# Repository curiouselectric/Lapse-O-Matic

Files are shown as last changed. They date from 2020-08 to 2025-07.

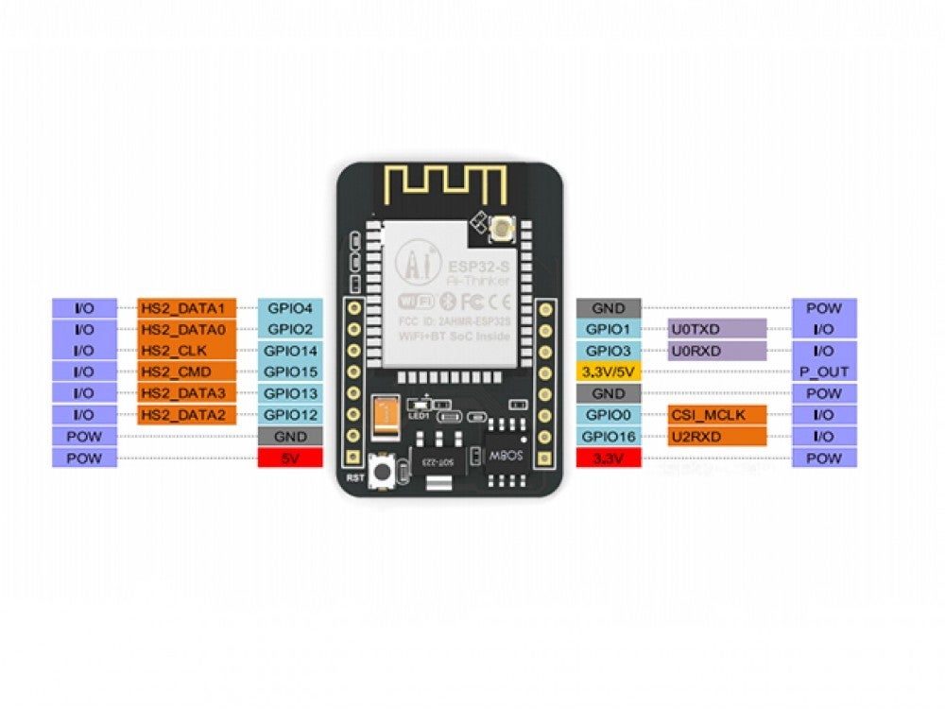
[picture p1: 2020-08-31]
Lapse-O-Matic_INFO/Datasheets/AI Tinker ESP32_CAM Info/ESP32_CAM_PINOUT.jpg

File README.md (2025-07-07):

# Solar Powered ESP32 Camera For Wildlife and Time-Lapse
This is code, PCB and enclosure design for an ESP32_CAM based, solar powered wildlife camera

This unit is based on the ESP32_CAM.

Code has been written to upload onto the ESP32.

Control of the unit is through a "settings.txt" file on the SD card.

The unit can either be in "LAPSE" mode (where it wakes up every set period and takes a photo/number of photos) or it can be in "TRIGGER" mode where it will take a number of photos when the unit is triggered. It will then go back to sleep.

Triggering can either be done with a PIR, or with an external switch.

This unit has an input for a small solar panel to recharge an 18650 Li Ion cell, so it can be left for remote monitoring.

A flash can be implemented, with a start and stop delay to adjust shadow effects.

This code relies heaviliy on the following tutorials and information:

* https://techtutorialsx.com/2020/06/27/esp32-connecting-to-sd-card/
* https://randomnerdtutorials.com/esp32-cam-take-photo-save-microsd-card/
* https://www.olimex.com/Products/IoT/ESP32/ESP32-CAM/
* https://marksbench.com/electronics/esp32-cam-low-power-trail-camera/
* https://hackaday.com/2020/05/18/esp32-trail-camera-goes-the-distance-on-aa-batteries/
* https://randomnerdtutorials.com/esp32-cam-ai-thinker-pinout/
* https://dronebotworkshop.com/esp32-cam-intro/

## ESP32 Code

Please follow these instructions for setting up your arduino IDE to upload code to the ESP32_CAM.

There is no USB connection to the ESP32_CAM, so I used this nice programmer from Tindie (around £10 UK):
https://www.tindie.com/products/bitluni/cam-prog/

The code starts by reading the settings.txt file on the root directoy of the SD card. If the SD card fails to mount, then the unit will go to default settings, which will mean sleeping for 10 seconds then trying the SD card again.
If there is no settings.txt file then the unit will use the default values (stored in the config.h page of the firmware).

## Settings file

Here is an example settings.txt file:

    // Adjust these settings as required: //
    FLASH_FLAG=1
    NUMBER_PHOTOS=4
    TIME_TO_SLEEP=800
    MODE=TRIGGER
    PHOTO_DELAY=250
    FLASH_START_DELAY=100
    FLASH_STOP_DELAY=100
    DEBUG_FLAG=1
    DEBUG_PHOTO=1
    // END OF SETTINGS - LEAVE THIS LINE  //

* FLASH_FLAG - Use a flash with the photo? (0 (OFF) or 1 (ON))
* NUMBER_PHOTOS - How many photos to take when waking up?
* TIME_TO_SLEEP - How long (in seconds) between wake-ups (when in SLEEP mode)
* MODE - The mode to use is either LAPSE (wake up every TIME_TO_SLEEP seconds) or TRIGGER (either wake up on PIR trigger or external trigger)
* PHOTO_DELAY - delay (in milli Seconds) between taking the photos.
* FLASH_START_DELAY - Flash will switch on then wait this time before taking photo (in milli Seconds)
* FLASH_STOP_DELAY - Flash will be on and wait this time after taking photo (in milli Seconds)
* DEBUG_FLAG - See debug info on serial port (0 (OFF) or 1 (ON))
* DEBUG_PHOTO - See debug info on serial port (0 (OFF) or 1 (ON))

*Note: Spaces can be used in the WIFI SSID. Do not use spaces around the equals sign.*

## Solar Power

This unit has a sinlge 18650 lithium polymer cell for power. This has a battery charging circuit using one cell PV module.

Based upon the BQ24210 800mA, single-input, single cell Li-ion Solar battery charger from Texas Instruments:

https://www.ti.com/sitesearch/docs/universalsearch.tsp?searchTerm=BQ24210#q=BQ24210&t=everything&linkId=1

## PCB design

PCB is designed in KiCAD.

A Real Time Clock (RTC) has been added to use as a timestamp on the photo files. This can also be used for the timing of the unit wake up.

## WiFi Upload

This unit uses ReadyMail from mobizt to send photos via an email SMTP server to any email address. You must set up your own email from which to send photos (I used gmail).

This is not always totally reliable, especially if any reception issues. But photos are still saved on the SD card.

## More information

There is lots more about this project at this blog post:

[*https://www.curiouselectric.co.uk/blogs/blog/prototyping-a-wildlife-camera**](https://www.curiouselectric.co.uk/blogs/blog/prototyping-a-wildlife-camera)

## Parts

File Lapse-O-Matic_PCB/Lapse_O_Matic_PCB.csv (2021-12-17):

Source: | G:\My Drive\Work - Kits\PRODUCTS\Prototype\Wildlife Camera\GITHUB\Wildlife_ESP_Cam\Wildlife_Cam_PCB\Lapse_O_Matic_PCB.sch
Date: | 19/08/2021 15:55:53
Tool: | Eeschema (5.1.10)-1
Component Count: | 38
Ref | Value | Footprint | Datasheet | Manufacturer | Vendor
C1 | 1uf | REInnovationFootprint:C_1V7_TH | ~
C3 | 1uf | REInnovationFootprint:C_1V7_TH | ~
D1 | ZENER | REInnovationFootprint:TH_Diode_3
D4 | TRIG? | REInnovationFootprint:TH_LED-5MM | ~
D5 | FLASH | REInnovationFootprint:TH_LED-5MM | ~
D6 | FLASH | REInnovationFootprint:TH_LED-5MM | ~
D7 | FLASH | REInnovationFootprint:TH_LED-5MM | ~
D8 | FLASH | REInnovationFootprint:TH_LED-5MM | ~
J1 | PIR | REInnovationFootprint:SIL-3_PIR_SENSOR | ~
J2 | TRIG | REInnovationFootprint:SIL-3_lg_pad | ~
J3 | RTC_DS3231 | REInnovationFootprint:TH_RTC_MODULE_SM | ~
J4 | PROG | REInnovationFootprint:TH_6x1_CONN | ~
J5 | PROG_EN | REInnovationFootprint:TH_Pin_Header_Straight_1x02 | ~
J6 | LOGO1 | CuriousElectric3:TCEC_Words_13mm | ~
J7 | LOGO2 | CuriousElectric3:2019_011_16_CuriousElectricCompany_Logo_Round_Logo_No_words_KiCAD_10mm_PCBLogo | ~
J8 | PCB | REInnovationFootprint:PCB_SolarChargerPCB40x80 | ~
J9 | LOGO3 | REInnovationGraphics:lapseomatic logo | ~
J10 | POWER | REInnovationFootprint:SIL-2_screw_terminal | ~
J11 | LOGO4 | REInnovationGraphics:lapseomatic logo_20x6mm | ~
Q1 | 2N3904 | REInnovationFootprint:NPN_BC337 | transistors/bipolar/*.*
Q2 | 2N3904 | REInnovationFootprint:NPN_BC337 | transistors/bipolar/*.*
Q3 | BD135 | REInnovationFootprint:TO220_BD135 | ~
R1 | 1k | REInnovationFootprint:TH_Resistor_1 | ~
R2 | 10k | REInnovationFootprint:TH_Resistor_1 | ~
R6 | 1k | REInnovationFootprint:TH_Resistor_1 | ~
R8 | 10k | REInnovationFootprint:TH_Resistor_1 | ~
R9 | 330 | REInnovationFootprint:TH_Resistor_1 | ~
R10 | 10k | REInnovationFootprint:TH_Resistor_1 | ~
R11 | 1k | REInnovationFootprint:TH_Resistor_1 | ~
R12 | 10k | REInnovationFootprint:TH_Resistor_1 | ~
R13 | 100 | REInnovationFootprint:TH_Resistor_1 | ~
R14 | 100 | REInnovationFootprint:TH_Resistor_1 | ~
R15 | 100 | REInnovationFootprint:TH_Resistor_1 | ~
R16 | 100 | REInnovationFootprint:TH_Resistor_1 | ~
SW1 | POWER | REInnovationFootprint:SW_SPDT_R_Angle_ALIEX
SW2 | TRIGGER | REInnovationFootprint:SW_PUSH_SMALL_lg_pad | ~
U1 | MCP1826S-3302 | REInnovationFootprint:TO220_MCP1826S | http://docs-europe.electrocomponents.com/webdocs/137e/0900766b8137eda2.pdf
U3 | ESP32_CAM | REInnovationFootprint:ESP32_CAM

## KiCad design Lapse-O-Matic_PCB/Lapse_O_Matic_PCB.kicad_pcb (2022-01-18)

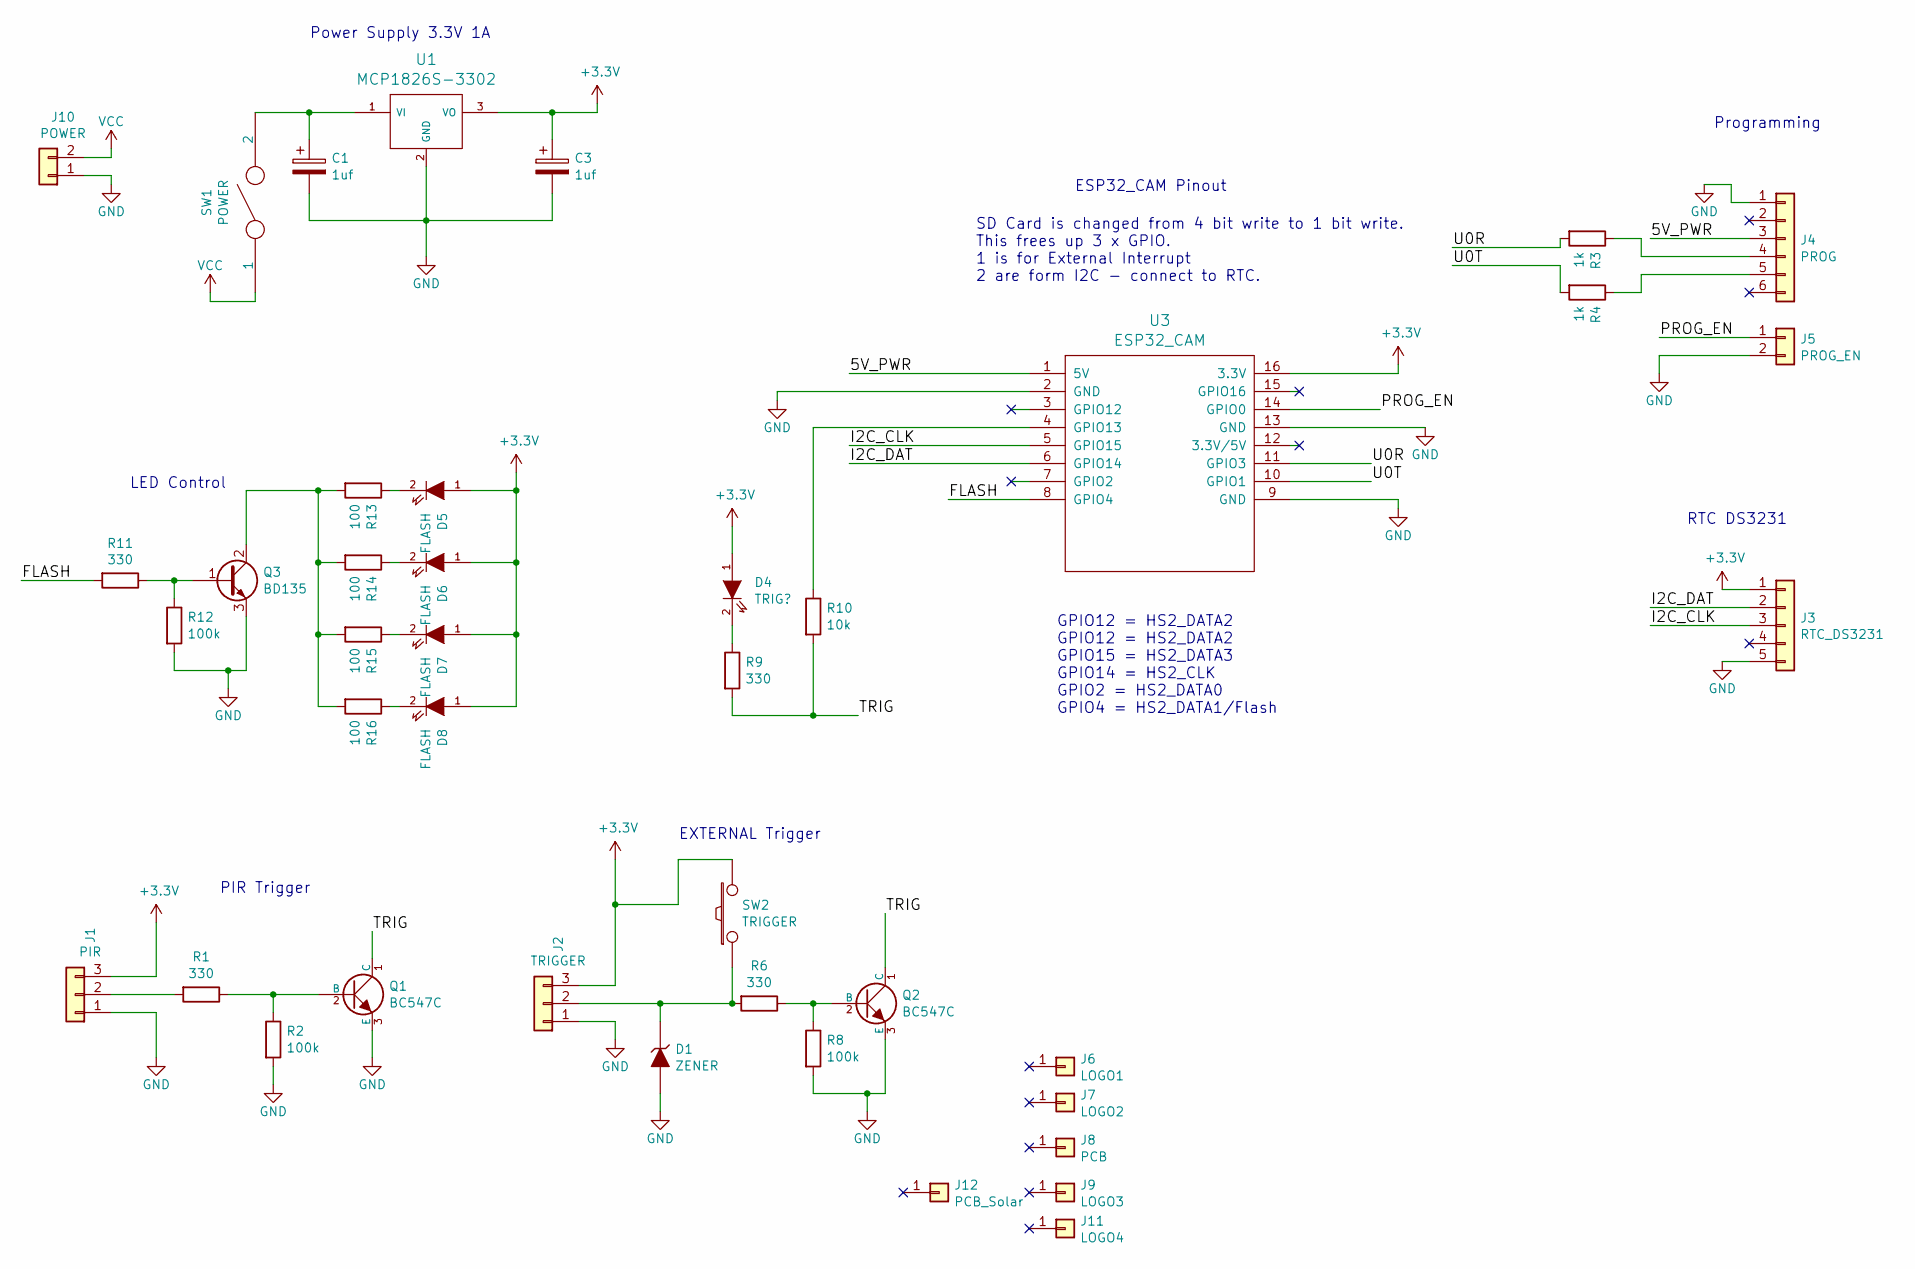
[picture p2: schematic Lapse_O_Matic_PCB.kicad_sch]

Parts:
C1, C3: 1uf; C_1V7_TH
D1: ZENER; TH_Diode_3
D4: TRIG?; TH_LED-5MM
D5, D6, D7, D8: FLASH; TH_LED-5MM
J1: PIR; SIL-3_PIR_SENSOR
J2: TRIGGER; SIL-3_screw_terminal
J3: RTC_DS3231; TH_RTC_MODULE_SM
J4: PROG; TH_6x1_CONN
J5: PROG_EN; TH_Pin_Header_Straight_1x02
J6: LOGO1; TCEC_Words_13mm
J7: LOGO2; 2019_011_16_CuriousElectricCompany_Logo_Round_Logo_No_words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
J8: PCB; PCB_Lapse-O-Matic
J9: LOGO3; lapseomatic logo_20x6mm
J10: POWER; SIL-2_screw_terminal
J11: LOGO4; lapseomatic logo_20x6mm
J12: PCB_Solar
Q1, Q2: BC547C; NPN_BC337
Q3: BD135; TO220_BD135
R1, R6, R9, R11: 330; TH_Resistor_1
R2, R8, R12: 100k; TH_Resistor_1
R3, R4: 1k; TH_Resistor_1
R10: 10k; TH_Resistor_1
R13, R14, R15, R16: 100; TH_Resistor_1
SW1: POWER; SW_SPDT_R_Angle_ALIEX
SW2: TRIGGER; SW_PUSH_SMALL_lg_pad
U1: MCP1826S-3302; TO220_MCP1826S
U3: ESP32_CAM

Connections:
+3V3: C3.1, D4.1 (A), D5.1 (A), D6.1 (A), D7.1 (A), D8.1 (A), J1.3, J2.3, J3.1, SW2.2, U1.3 (VO), U3.16 (3.3V)
/5V_PWR: J4.3, U3.1 (5V)
/FLASH: R11.2, U3.8 (GPIO4)
/I2C_CLK: J3.3, U3.5 (GPIO15)
/I2C_DAT: J3.2, U3.6 (GPIO14)
/PROG_EN: J5.1, U3.14 (GPIO0)
/TRIG: Q1.1 (C), Q2.1 (C), R9.2, R10.2
/U0R: R3.2, U3.11 (GPIO3)
/U0T: R4.2, U3.10 (GPIO1)
GND: C1.2, C3.2, D1.2 (A), J1.1, J2.1, J3.5, J4.1, J5.2, J10.1, Q1.3 (E), Q2.3 (E), Q3.3 (E), R2.2, R8.2, R12.2, U1.2 (GND), U3.2 (GND), U3.9 (GND), U3.13 (GND)
unnamed: C1.1, SW1.2, U1.1 (VI)
unnamed: D1.1 (K), J2.2, R6.2, SW2.1
unnamed: D4.2 (K), R9.1
unnamed: D5.2 (K), R13.1
unnamed: D6.2 (K), R14.1
unnamed: D7.2 (K), R15.1
unnamed: D8.2 (K), R16.1
unnamed: J1.2, R1.2
unnamed: J4.4, R3.1
unnamed: J4.5, R4.1
unnamed: Q1.2 (B), R1.1, R2.1
unnamed: Q2.2 (B), R6.1, R8.1
unnamed: Q3.1 (B), R11.1, R12.1
unnamed: Q3.2 (C), R13.2, R14.2, R15.2, R16.2
unnamed: R10.1, U3.4 (GPIO13)
VCC: J10.2, SW1.1

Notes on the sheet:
LED Control
RTC DS3231
Programming
ESP32_CAM Pinout
PIR Trigger
Power Supply 3.3V 1A
SD Card is changed from 4 bit write to 1 bit write. This frees up 3 x GPIO. 1 is for External Interrupt 2 are form I2C - connect to RTC.
EXTERNAL Trigger
GPIO12 = HS2_DATA2 GPIO12 = HS2_DATA2 GPIO15 = HS2_DATA3 GPIO14 = HS2_CLK GPIO2 = HS2_DATA0 GPIO4 = HS2_DATA1/Flash

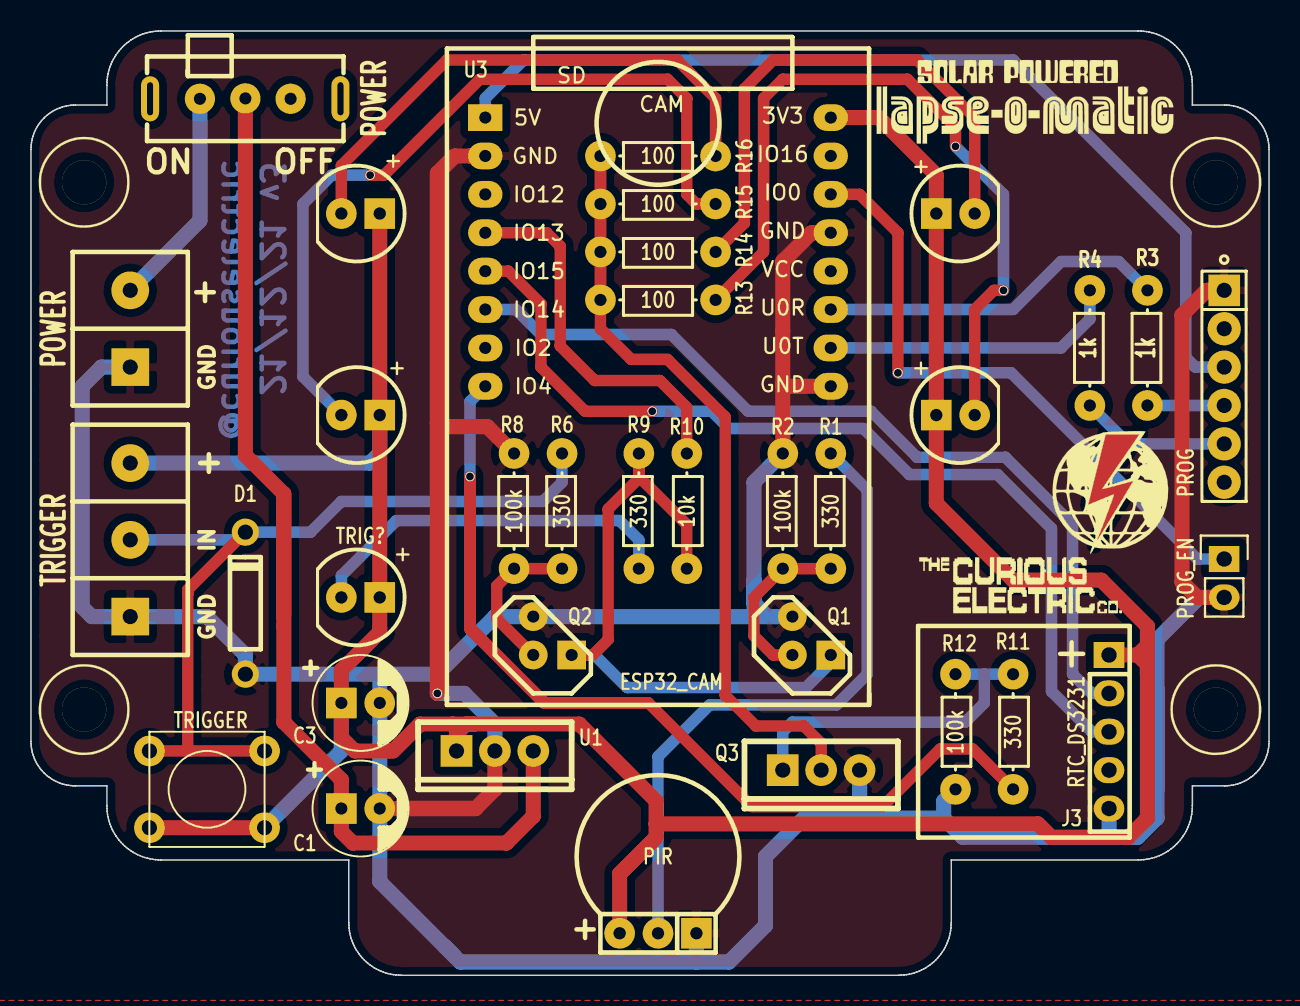
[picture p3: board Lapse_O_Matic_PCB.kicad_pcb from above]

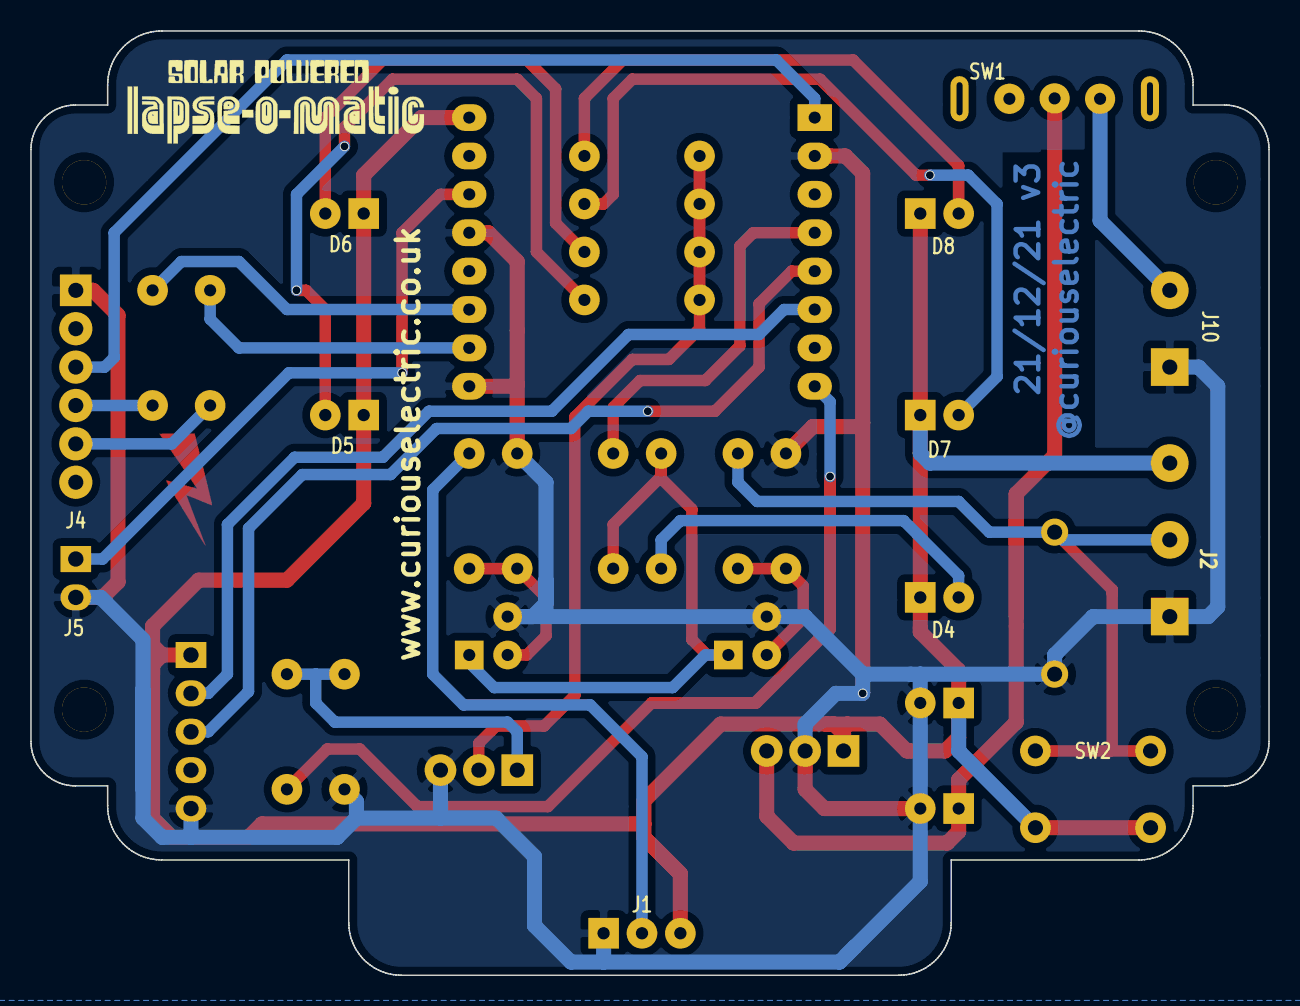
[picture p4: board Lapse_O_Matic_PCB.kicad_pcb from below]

Board: 2 copper layers, 81.9 x 62.5 mm, 40 parts (3 on the bottom side), 26 nets.

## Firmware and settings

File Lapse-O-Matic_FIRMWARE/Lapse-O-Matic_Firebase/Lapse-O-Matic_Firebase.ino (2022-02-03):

/* ********* ESP32_CAM Wildlife Camera Unit **************************

    by Matt Little
    The Curious Electric Company (www.curiouselectric.co.uk)
    hello@curiouselectric.co.uk
    17/12/2021
    This code is Open Source - please adjust and use as you would like.
    Please ensure accreditation
    (although most of this code is based on work of others - see list below).

    More information (full files and firmware) is here:
    https://github.com/curiouselectric/Lapse-O-Matic

    Idea for this code:
    Unit is solar powered with a lithium ion battery bank 18650 cell
    Unit wakes up with a PIR sensor or with external interrupt (via switched contacts) or via sleep mode.
    Reads each time the config file from the SD card - this tells it what mode to run in and other parameters.
    Need a "settings.config.txt" file on the SD card with thes config values.

    At that point the unit takes a number of photos with a delay between them
    Unit can wake up with either LAPSE or TRIGGER.
    LAPSE will be every LAPSE seconds. TRIGGER will be on PIR or external switch.

    It uses a real time clock (RTC) to add a timestamp to the photo image.
    It will update the RTC to NTP time (UTC) if the unit connects to wifi at any point.
    This is checked each time it connects.

    This code now uploads the image(s) to Firebase (https://firebase.google.com/) for photo storage.
    Following this tutorial (caefully) for setting up your firebase account and details:
    https://randomnerdtutorials.com/esp32-cam-save-picture-firebase-storage/

    ***TO PROGRAM: Set Board to "AI Thinker ESP32-CAM"***

    Some Information that has been very useful
    https://randomnerdtutorials.com/esp32-cam-take-photo-save-microsd-card/
    https://www.olimex.com/Products/IoT/ESP32/ESP32-CAM/
    https://marksbench.com/electronics/esp32-cam-low-power-trail-camera/
    https://hackaday.com/2020/05/18/esp32-trail-camera-goes-the-distance-on-aa-batteries/
    https://randomnerdtutorials.com/esp32-cam-ai-thinker-pinout/
    https://dronebotworkshop.com/esp32-cam-intro/

    This new code uploads to firebase. Following this tutotorial:
    https://randomnerdtutorials.com/esp32-cam-save-picture-firebase-storage/

    Must include:
    Firebase Arduino Client Library for ESP8266 and ESP32 by Mobitz
    https://github.com/mobizt/Firebase-ESP-Client


    Done:
    Sort out the LED on (at low glow level)? - This is solved.
    Sort out flash LED - only works on first reprogram - This is solved.
    Sort out interrupt via PIR unit - This is solved.
    Flash on/off (boolean ) is not working? - Sorted
    Sort out RTC for file name - done. I2C shared pins.
    Sort out file names.
    Sort out reprogramming with FTDI/USB
    Sort out running all at 3.3V. Works with low drop out regulator.
    What happens if no RTC connected? - reverts to other filename with a counter
    Report Error to log file. - this happens when camera does not start with timestamp
    if no RTC: need to sort out naming as it's overwriting the same one. - DONE
    Send photos via email if on wifi (https://randomnerdtutorials.com/esp32-cam-send-photos-email/)
    https://rntlab.com/question/esp32-cam-send-email-with-attachment-from-sd-card-problem-no-attachment-in-email/
    Issue with SD_MMC and sending info with SD.
    Need to change to use SD_MMC for 1-bit writing to SD card

    To do:
    Need error feedback - flash 1 for OK, 2 for internet not OK, 3 for SD error, 5 for camera sync error
    Add configuration via WifiManager (?)
    Add voltage measurement to check battery is OK - ADC? - Not easy with so few IO pins
    Shut down everything in sleep mode - at present using 5.8mA in Sleep!!!

    Sleep issues:
    Takes around 5mA (actually 4.6mA)
    Looks like LDO is issue:
    https://diyi0t.com/reduce-the-esp32-power-consumption/
    https://www.hackster.io/dontsovcmc/esp32-cam-current-measure-87c18f
    I dont need LDO on my board, as I already have one!
    Removed LDO - down to 2.6mA
    Removed camera - down to 0.47mA // Can I set GPIO to switch this off?

    Added this line:
    pinMode(OUTPUT_OPEN_DRAIN, GPIO_NUM_12);pinMode(OUTPUT_OPEN_DRAIN, GPIO_NUM_15);
    Now down to about 1.9mA 2.4mA (maybe 2.4mA after a while)

    Need to shut down the camera - uses about 1.9mA all the time...
    digitalWrite(PWDN_GPIO_NUM, HIGH);
    Does not do anything
    https://issueexplorer.com/issue/espressif/esp32-camera/247

    From this:
    https://github.com/espressif/esp32-camera/issues/33
    camera_disable_out_clock();
    and in camera config
    extern "C" { esp_err_t camera_enable_out_clock(camera_config_t *config); void camera_disable_out_clock(); }
    This does not seem to do much!

*/

#include <esp_camera.h>
#include <FS.h>
#include <SPI.h>
#include "SD_MMC.h"
#include <Preferences.h>
#include <Arduino.h>
#include <SPIFFS.h>
#include <WiFi.h>

#include <Firebase_ESP_Client.h>
//Provide the token generation process info.
#include <addons/TokenHelper.h>

#include "config.h"
#include "camera_pins.h"
#include "Esp.h"
#include "utilitiesDL.h"
#include "lapseomatic.h"

#include "driver/sdmmc_host.h"
#include "driver/sdspi_host.h"

// Date and time functions using a DS3231 RTC connected via I2C and Wire lib
#include <Wire.h>
#include "RTClib.h"
#include "time.h"
RTC_DS3231 rtc;

#include "soc/soc.h"           // Disable brownout problems
#include "soc/rtc_cntl_reg.h"  // Disable brownout problems
#include "driver/rtc_io.h"

// The ESP32 EEPROM library is deprecated. Use the Preferences library instead.
Preferences preferences;
settings  settings_config;              // This holds the settings info from the SD card
// Configure the camera with the pins defined above and recommended settings for xclk, led_c, and format.
camera_config_t config;

// Create a variable to hold the picture number. Since the SD card is formatted FAT32, the maximum number of files
// there can be is 65534, so a 16-bit unsigned number will be fine.
// Want to store this in 'sleep' protected memory
uint16_t PIC_COUNT = 0;
String filename = "";       // This holds the date string for the filename.

String PHOTO_NAME[5];          // Holds the name of the photo to send. Actually want array of names of photos to send.... Max photos to send = 5

//Define Firebase Data objects
FirebaseData fbdo;
FirebaseAuth auth;
FirebaseConfig configF;

// For NTP time server
const char* ntpServer = "pool.ntp.org";
const long  gmtOffset_sec = 0;
const int   daylightOffset_sec = 0;


void setup()
{
  WRITE_PERI_REG(RTC_CNTL_BROWN_OUT_REG, 0);  //disable brownout detector
  Serial.begin(115200);
  //Print the wakeup reason for ESP32
  print_wakeup_reason();
  DEBUGLN(settings_config.DEBUG_FLAG, "Starting");
  switch_off_flash_LED(); // Ensure LED is OFF to start.

  bool rtc_flag = true;

  initSPIFFS();
  clearSPIFFS();  // If files in SPIFFS then delete them!

  // Lets try reading/writing to I2C
  // Start the I2C interface
  if (! Wire.begin(I2C_SDA, I2C_SCL)) {
    // If the RTC does not start,
    // Then carry on, but without correct filename.
    DEBUGLN(settings_config.DEBUG_FLAG, "Couldn't find RTC");
    rtc_flag = false;
  }

  if (! rtc.begin()) {
    // If the RTC does not start, wait for a little while (1 sec?)
    // Then carry on, but without correct filename.
    delay(200);
    DEBUGLN(settings_config.DEBUG_FLAG, "Couldn't find RTC");
    rtc_flag = false;
    //abort();
  }
  if (rtc_flag == true)
  {
    if (rtc.lostPower())
    {
      // Here we get the date and time from the SD card??
      DEBUGLN(settings_config.DEBUG_FLAG, "RTC lost power, let's set the time!");
      // When time needs to be set on a new device, or after a power loss, the
      // following line sets the RTC to the date & time this sketch was compiled
      rtc.adjust(DateTime(F(__DATE__), F(__TIME__)));
      // This line sets the RTC with an explicit date & time, for example to set
      // January 21, 2014 at 3am you would call:
      //rtc.adjust(DateTime(2020, 12, 5, 11, 44, 0));
    }
    DateTime now = rtc.now();
    // Set the date with date and time with the data, to use as filename later.
    filename = "D" + (String)now.year() + "_" + (String)now.month() + "_" +
               (String)now.day() + "_T" + (String)now.hour() + "_" + (String)now.minute() + "_" + (String)now.second();
  }
  else
  {
    // RTC is not attached so cannot use it!
    filename = "NO_RTC_";
  }

  // *************** SORT OUT THE SD CARD ****************************** //
  // Start up the SD card, using 1-bit xfers instead of 4-bit (set the "true" option).
  // Frees up GPIO13.
  switch_on_flash_LED();
  delay(10);

  if (!SD_MMC.begin("/sdcard", true))
  {
    // If we're here, there's a problem with the SD card.
    DEBUGLN(settings_config.DEBUG_FLAG, "SD Card Mount Fail");
    // We flash the LED to show an SD card error
    flash_error(3); // Flash 3 times for an SD card mount error
    // This checks the mode the unit is in and then goes to sleep accordingly
    check_mode_then_sleep();
  }


  // Query the card to make sure it's OK
  uint8_t SD_CARD = SD_MMC.cardType();
  DEBUG(settings_config.DEBUG_FLAG, "Card Type:");

  if (SD_CARD == CARD_NONE) {
    // If we're here, there's a problem with the SD card.
    DEBUGLN(settings_config.DEBUG_FLAG, "No SD Card!");
    // Flash the LED to highlight this:
    flash_error(10);
    // This checks the mode the unit is in and then goes to sleep accordingly
    check_mode_then_sleep();

  } else if (SD_CARD == CARD_MMC) {
    DEBUGLN(settings_config.DEBUG_FLAG, "MMC");
  } else if (SD_CARD == CARD_SD) {
    DEBUGLN(settings_config.DEBUG_FLAG, "SDSC");
  } else if (SD_CARD == CARD_SDHC) {
    DEBUGLN(settings_config.DEBUG_FLAG, "SDHC");
  } else {
    DEBUGLN(settings_config.DEBUG_FLAG, "UNKNOWN");
  }
  // We are now done the setup and should be ready to take pictures
  // in the main loop() function.

  // Here we read the settings file from the SD card.
  // This will change any default settings defined
  readSettings(SD_MMC, SETTINGS_FILENAME, settings_config);


  // ************** START UP THE CAMERA ********************** //

  preferences.begin("trailcam", false); // Open nonvolatile storage (EEPROM) on the ESP in RW mode

  PIC_COUNT = preferences.getUShort("PIC_COUNT", 0);  // Get the stored picture count from the EEPROM.
  // Return 0 if it doesn't exist.
  // getUShort() fetches a 16-bit unsigned value
  // We add the Picture Count to give unique ID to the photoname
  configure_camera(config, settings_config);

  // Start up the camera with the configuration settings made earlier in the "config." statements.
  esp_err_t err = esp_camera_init(&config);

  if (err != ESP_OK) {
    // If we're here, there's a problem communicating with the camera.
    DEBUGLN(settings_config.DEBUG_FLAG, "CAMERA ERROR");

    if (settings_config.DEBUG_FLAG == 1)
    {
      Serial.printf("CAMERA ERROR: 0x%x", err);
    }
    // If this happens want to write a line to the error log file.
    // If possible add the date/time to this log file.
    fs::FS &fs = SD_MMC;

    // Now, create a new file using the path and name set above.
    File file = fs.open((String)ERROR_FILENAME, FILE_APPEND);
    if (!file) {
      // If we're here, there's a problem creating a new file on the SD card.
      DEBUGLN(settings_config.DEBUG_FLAG, "Error with opening Error file on SD");
      // This checks the mode the unit is in and then goes to sleep accordingly
      check_mode_then_sleep();
    }
    else
    {
      DEBUGLN(settings_config.DEBUG_FLAG, ("Error on : " + filename + " Code: " + err));
      // Write to file
      // If we're here, the file was created. Now write the captured image to the file.
      file.println("Error on : " + filename );
    }
    file.close(); // Done writing the file so close it.

    // We flash the LED to show an SD card error
    flash_error(5); // Flash 5 times for an camera sync error

    // This checks the mode the unit is in and then goes to sleep accordingly
    check_mode_then_sleep();
    return;
  }
}

void loop()
{
  uint8_t COUNTUP = 1;  // Create variable to take multiple pictures.
  while (COUNTUP <= settings_config.NUMBER_PHOTOS)
  {
    // Take number_photos pictures before shutting down.
    if (settings_config.FLASH_FLAG == true)
    {
      switch_on_flash_LED();
      digitalWrite(LED_FLASH_PIN, HIGH);
      delay(settings_config.FLASH_START_DELAY);
    }
    // Take picture and read the frame buffer
    camera_fb_t * fb = esp_camera_fb_get();

    if (settings_config.FLASH_FLAG == true)
    {
      delay(settings_config.FLASH_STOP_DELAY);
      digitalWrite(LED_FLASH_PIN, LOW);
    }
    if (!fb)
    {
      // This checks the mode the unit is in and then goes to sleep accordingly
      check_mode_then_sleep();
    }
    // Image captured: Save it here:
    // Want to use the date & time for the file name - to log it.

    String path;
    if (filename == "NO_RTC_")
    {
      path = "/" + filename + (String)PIC_COUNT + "_" + String(COUNTUP) + "_of_" + String(settings_config.NUMBER_PHOTOS) + ".jpg";
    }
    else
    {
      path = "/" + filename + "_" + String(COUNTUP) + "_of_" + String(settings_config.NUMBER_PHOTOS) + ".jpg";
    }
    PHOTO_NAME[COUNTUP] = path;
    if (settings_config.DEBUG_FLAG == 1)
    {
      Serial.print("Photo Path: ");
      Serial.println(PHOTO_NAME[COUNTUP]);
    }

    fs::FS &fs = SD_MMC;


    // Now, create a new file using the path and name set above.
    File file = fs.open(path.c_str(), FILE_WRITE);

    if (!file) {
      // If we're here, there's a problem creating a new file on the SD card.
      DEBUGLN(settings_config.DEBUG_FLAG, "Error wth creating file on SD");
      // This checks the mode the unit is in and then goes to sleep accordingly
      // We flash the LED to show an SD card error
      flash_error(3); // Flash 3 times for an SD error
      check_mode_then_sleep();
    }
    else
    {
      // If we're here, the file was created. Now write the captured image to the file.
      file.write(fb->buf, fb->len);
      // Here we increment the picture number
      PIC_COUNT = PIC_COUNT + 1;  // Increment the picture count number each time there's a successful write.
      if (PIC_COUNT >= 65500) {
        PIC_COUNT = 0;            // FAT32 has a limit of 65534 files in a folder
      }
    }
    file.close(); // Done writing the file so close it.

    // Free the memory used by the framebuffer so it's available for another picture
    esp_camera_fb_return(fb);
    delay(settings_config.PHOTO_DELAY); // Wait between photos - adjustable
    COUNTUP = COUNTUP + 1;  // We are done an image capture cycle. Increment the count.
  }

  // If we're here then we've taken the pictures and we are ready to shut down.
  // Write the current file number to the EEPROM
  preferences.putUShort("PIC_COUNT", PIC_COUNT);  // Store the picture count number in the EEPROM

  // If there is data in the wifi SSID then try to connect to wifi.
  // Else we go to sleep

  if (settings_config.WIFI_SSID.length() != 0)
  {
    // In this case we have an SSID so try to connect to WiFi
    char ssid[settings_config.WIFI_SSID.length() + 2];
    settings_config.WIFI_SSID.toCharArray(ssid, settings_config.WIFI_SSID.length() + 1);
    char pass[settings_config.WIFI_PASS.length() + 2];
    settings_config.WIFI_PASS.toCharArray(pass, settings_config.WIFI_PASS.length() + 1);
    if (settings_config.DEBUG_FLAG == 1)
    {
      Serial.print("SSID: ");
      Serial.print(ssid);
      Serial.print(" PW: ");
      Serial.println(pass);
    }
    // ******** SEND IMAGE via WIFI *****************************
    // Connect to Wi-Fi
    WiFi.begin(ssid, pass);
    Serial.print("Connecting to WiFi...");
    int timeout_wifi = 0;
    while (WiFi.status() != WL_CONNECTED && timeout_wifi < 20) {
      delay(500);
      Serial.print(".");
      timeout_wifi++;
    }
    if (timeout_wifi < 20)
    {
      // This means we have connected within 10 seconds, else timeout...
      Serial.println("Connected to WiFi");
      // Print ESP32 Local IP Address
      Serial.print("IP Address: http://");
      Serial.println(WiFi.localIP());
      sendPhoto();
      checkRTC();
      flash_error(1); // Show that we have sent the email OK
    }
  }
  
  if (settings_config.PIR_ENABLE == 1)
  {
    // only need to do this if using PIR
    // Switch off wifi:
    WiFi.setSleep(true);
    // as the PIR is triggering due to the wifi activity, need to have a decent delay here after switching off wifi
    delay(10000);  //10 s delay before retrigger on PIR.
  }
  
  // This checks the mode the unit is in and then goes to sleep accordingly
  check_mode_then_sleep();
}

void switch_off_gpio()
{
  // switch off all GPIO to stop consuming power
  pinMode(OUTPUT_OPEN_DRAIN, GPIO_NUM_12);
  pinMode(OUTPUT_OPEN_DRAIN, GPIO_NUM_15);

  //  pinMode(OUTPUT_OPEN_DRAIN, CAM_PIN_XCLK);
  //  digitalWrite(CAM_PIN_XCLK, LOW);

  //digitalWrite(CAM_PIN_PWDN, HIGH);
  gpio_set_level(GPIO_NUM_32, 1);
  gpio_set_level(GPIO_NUM_0, 0);
  gpio_deep_sleep_hold_en();

  //  pinMode(OUTPUT_OPEN_DRAIN, CAM_PIN_SIOD);
  //  pinMode(OUTPUT_OPEN_DRAIN, CAM_PIN_SIOC);
  //  pinMode(OUTPUT_OPEN_DRAIN, CAM_PIN_D7);
  //  pinMode(OUTPUT_OPEN_DRAIN, CAM_PIN_D6);
  //  pinMode(OUTPUT_OPEN_DRAIN, CAM_PIN_D5);
  //  pinMode(OUTPUT_OPEN_DRAIN, CAM_PIN_D4);
  //  pinMode(OUTPUT_OPEN_DRAIN, CAM_PIN_D3);
  //  pinMode(OUTPUT_OPEN_DRAIN, CAM_PIN_D2);
  //  pinMode(OUTPUT_OPEN_DRAIN, CAM_PIN_D1);
  //  pinMode(OUTPUT_OPEN_DRAIN, CAM_PIN_D0);
  //  pinMode(OUTPUT_OPEN_DRAIN, CAM_PIN_VSYNC);
  //  pinMode(OUTPUT_OPEN_DRAIN, CAM_PIN_HREF);
  //  pinMode(OUTPUT_OPEN_DRAIN, CAM_PIN_PCLK);

}

void enable_sleep()
{
  switch_off_flash_LED();

  delay(10);
  //   Now go to sleep:
  esp_sleep_enable_timer_wakeup(settings_config.TIME_TO_SLEEP * uS_TO_S_FACTOR);
  switch_off_gpio();

  Serial.println("Setup ESP32 to sleep for " + String(settings_config.TIME_TO_SLEEP) + " Seconds");
  Serial.println("ZZZZzzzzz....");
  Serial.flush();
  esp_deep_sleep_start();
  Serial.println("This will never be printed");
}

void enable_trigger()
{
  switch_off_flash_LED();

  delay(10);

  //   Now go to sleep:
  esp_sleep_enable_ext0_wakeup(GPIO_PIN_WAKEUP, 0);
  switch_off_gpio();

  Serial.println("Setup ESP32 to sleep Until Trigger on GPIO 13");
  Serial.println("ZZZZzzzzz....");
  Serial.flush();
  esp_deep_sleep_start();
  Serial.println("This will never be printed");
}

void check_mode_then_sleep()
{
  // Here we either enable sleep or attach an interrupt....
  // depends upon mode_type
  // What mode are we in?
  Serial.print("Mode is: ");
  Serial.println(settings_config.MODE);
  String mode_string = settings_config.MODE;
  if (mode_string.indexOf(String("LAPSE")) >= 0)
  {
    Serial.println("ZZZZzzzzz....");
    enable_sleep();
  }
  else if (mode_string.indexOf(String("TRIGGER")) >= 0)
  {
    Serial.println("Trigger Mode. Attach Interrupt. Then Sleep");
    enable_trigger();
  }
  else
  {
    Serial.println("Mode invalid. Still going to sleep...");
    enable_sleep();
  }
}
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

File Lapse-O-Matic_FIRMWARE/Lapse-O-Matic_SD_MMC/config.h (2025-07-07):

#pragma once

#include "utilitiesDL.h"

//
// WARNING!!! Make sure that you have either selected ESP32 Wrover Module,
//            or another board which has PSRAM enabled
//

// ***TO PROGRAM: Set Board to "AI Thinker ESP32-CAM"***
// Select camera model
//#define CAMERA_MODEL_WROVER_KIT
//#define CAMERA_MODEL_ESP_EYE
//#define CAMERA_MODEL_M5STACK_PSRAM
//#define CAMERA_MODEL_M5STACK_WIDE
#define   CAMERA_MODEL_AI_THINKER

//#define   IMAGE_QUALITY       10    // Set via SD card
#define   IMAGE_SIZE          FRAMESIZE_UXGA
    // The following resolutions are available:
    // 96x96 (96x96)
    // QQVGA (160x120)
    // QQVGA2 (128x160)
    // QCIF (176x144)
    // HQVGA (240x176)
    // 240x240 (240x240)
    // QVGA (320x240)
    // CIF (400x296)
    // VGA (640x480)
    // SVGA (800x600)
    // XGA (1024x768)
    // SXGA (1280x1024)
    // UXGA (1600x1200) **Full-resolution for OV2640

// ******** DEFAULT SETTINGS ARE ADDED HERE ********//

#define   WIFI_TIMEOUT        10        // Number of seconds before doing wifi timeout
#define   SETTINGS_FILENAME   "/settings.txt"
#define   ERROR_FILENAME      "/error.txt"

#define   LED_FLASH_PIN       GPIO_NUM_4           // GPIO pin for the flash LED
#define   LED_ONBOARD         GPIO_NUM_33          // GPIO pin for the on-board LED
#define   GPIO_PIN_WAKEUP     GPIO_NUM_13

#define   I2C_SCL             GPIO_NUM_15
#define   I2C_SDA             GPIO_NUM_14

#define   SD_CLK              GPIO_NUM_14
#define   SD_CMD              GPIO_NUM_15
#define   SD_DATA0            GPIO_NUM_2

#define   uS_TO_S_FACTOR      1000000ULL  /* Conversion factor for micro seconds to seconds */

static const char *name_array[] = { "FLASH_FLAG", "FLASH_START_DELAY", "FLASH_STOP_DELAY", "DEBUG_FLAG",
                                    "DEBUG_PHOTO", "NUMBER_PHOTOS", "TIME_TO_SLEEP", "MODE", "PHOTO_DELAY",
                                    "WIFI_SSID", "WIFI_PASS", "AUTHOR_EMAIL", "AUTHOR_PASSWORD", "SMTP_HOST",
                                    "SMTP_PORT", "RECIPIENT_EMAIL", "EMAIL_SUBJECT", "IMAGE_QUALITY"
                                  };

#include <Arduino.h>

class settings {
  public:
    bool          FLASH_FLAG = 1;         // 0 for off, 1 for on
    int           FLASH_START_DELAY = 10; // mS to switch on light before taking photo - adjust for best quality
    int           FLASH_STOP_DELAY = 10;  // mS to switch on light before taking photo - adjust for best quality
    bool          DEBUG_FLAG = 1;
    bool          DEBUG_PHOTO = 1;
    unsigned int  NUMBER_PHOTOS = 1;
    unsigned int  TIME_TO_SLEEP = 10;
    String        MODE = "TRIGGER";       // "LAPSE" is for sleep mode, with info below
    // "TRIGGER" is for PIR/external trigger mode
    unsigned int  PHOTO_DELAY = 500;      // mS between photos (approx, due to photo time)
    String        WIFI_SSID;
    String        WIFI_PASS;
    String        AUTHOR_EMAIL;
    String        AUTHOR_PASSWORD;
    String        SMTP_HOST;
    int           SMTP_PORT = 465;
    String        RECIPIENT_EMAIL;
    String        EMAIL_SUBJECT = "Lapse-O-Matic";
    int           IMAGE_QUALITY = 12;
    // Valid: 0-63, with 0 being highest quality and largest file size.
    // Anything lower than 8 creates large file sizes that take a long time
    // to save to the SD card.
    // The camera and lens aren't the best quality, so huge files
    // won't get you a better picture beyond a certain point.
};

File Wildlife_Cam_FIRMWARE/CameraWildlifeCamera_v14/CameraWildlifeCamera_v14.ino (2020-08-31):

/* Some Information that might be useful

    https://randomnerdtutorials.com/esp32-cam-take-photo-save-microsd-card/
    https://www.olimex.com/Products/IoT/ESP32/ESP32-CAM/
    https://marksbench.com/electronics/esp32-cam-low-power-trail-camera/
    https://hackaday.com/2020/05/18/esp32-trail-camera-goes-the-distance-on-aa-batteries/
    https://randomnerdtutorials.com/esp32-cam-ai-thinker-pinout/
    https://dronebotworkshop.com/esp32-cam-intro/

    Idea for this code:

    Unit is solar powered with a lithium ion battery bank 18650 cell
    Unit wakes up with a PIR sensors (?) or with external interrupt (via switched contacts) or via sleep mode.

    Reads each time the config file from the SD card - this tells it what mode to run in and other parameters.

    Need a "settings.config.txt" file on the SD card.

    At that point the unit takes a clip of X seconds (adjustable) at a frame rate of Y (adjustable)

    PIR sensor information:
    Found some 3.3V PIR sensors - use those!
    Trigger neds to go through an NPN transistor.

    Solar Recharge info:
    I used the 18650 1-cell breakout board I'd made
    This has an 18650 cell available, but will need a ncie regulated 3.3V for the ESP32-Cam?

    To do:
    Sort out the LED on (at low glow level)? - This is solved.
    Sort out flash LED - only works on first reprogram

    Sort out interrupt via PIR unit
    Sort out running all at 3.3V?

    Sort out reprogramming with FTDI/USB



 *  ***TO PROGRAM: Set Board to "AI Thinker ESP32-CAM"***
 *  */
/* ESP32-CAM Low Power Trail Camera v1
   Mark's Bench (http://marksbench.com)
   Uses ESP32-Cam AI-Thinker with OV2640 camera to take pictures and save to SD card when triggered by PIR
   ESP32 is connected to power rail via MOSFET. MOSFET is initially turned on by PIR trigger and kept on by setting pin D13
   on the ESP32 high as soon as ESP starts up.

   ESP then takes 5 pictures and saves them to the SD card, after which it sets D13 low, which turns the MOSFET off,
   cutting the ESP off from the GND rail.

   If the PIR trigger remains high or goes high again during when the ESP32 would shut down, then take another five
   pictures and try shutting down again.

   Advantage to this scheme is a power savings - power draw is less than 20uA when the MOSFET
   is off and the ESP32 is shut down. Power draw is around 130-140mA when pictures are being taken and saved.

   Disadvantage is that when using both the camera and the SD card, there are no easily usable GPIO pins available.
   To get around this, use 1-bit SD card access instead of the usual 4-bit.
   It slows things down but you can still get an image with ok quality about once a second
   at full resolution (1600x1200) on the OV2640.

   Information on and code examples for using the ESP32-CAM library:
   https://github.com/yoursunny/esp32cam
   https://github.com/espressif/esp32-camera
   https://github.com/espressif/arduino-esp32/tree/master/libraries/ESP32/examples/Camera/CameraWebServer

   Information on and code examples for using the ESP32 SD_MMC library:
   https://github.com/espressif/arduino-esp32/tree/master/libraries/SD_MMC

   Information on using the ESP32 EEPROM (the Preferences library):
   https://github.com/espressif/arduino-esp32/tree/master/libraries/Preferences

   VERY useful ESP32 documentation:
   https://www.espressif.com/en/support/download/documents
   In particular, the "ESP32-WROOM-32 Datasheet", "ESP32 Datasheet", and "ESP32 Hardware Design Guidelines".
   Also, the schematic at:
   https://github.com/SeeedDocument/forum_doc/raw/master/reg/ESP32_CAM_V1.6.pdf
   And the specification page (which has some errors) at:
   https://github.com/raphaelbs/esp32-cam-ai-thinker/blob/master/assets/ESP32-CAM_Product_Specification.pdf

  // https://techtutorialsx.com/2020/06/27/esp32-connecting-to-sd-card/
  // In short, the SD library operates over SPI and the SD_MMC uses the SDMMC hardware bus
  // of the ESP32 [1]. So, depending on your hardware setup, you should choose the correct
  // library. For the board I’m using, I need to use the SC_MMC one.


*/

#include "config.h"
#include "camera_pins.h"
#include "Esp.h"
#include "utilitiesDL.h"

#include <esp_camera.h>
#include <FS.h>
#include <SPI.h>
#include <SD_MMC.h>
#include <Preferences.h>

#include "soc/soc.h"           // Disable brownour problems
#include "soc/rtc_cntl_reg.h"  // Disable brownour problems
#include "driver/rtc_io.h"

// The ESP32 EEPROM library is deprecated. Use the Preferences library instead.
Preferences preferences;


// ******* Global Variables ********

bool flash_flag = FLASH_FLAG;
int flash_start_delay = FLASH_START_DELAY;
int flash_stop_delay = FLASH_STOP_DELAY;
bool debug_flag = DEBUG_FLAG;
bool debug_photo = DEBUG_PHOTO;
unsigned int number_photos = NUMBER_PHOTOS;
unsigned int  time_to_sleep = TIME_TO_SLEEP;
String mode_type = MODE;
unsigned int photo_delay = PHOTO_DELAY;

char *name_array[] = { "FLASH_FLAG", "FLASH_START_DELAY", "FLASH_STOP_DELAY",
                       "DEBUG_FLAG", "DEBUG_PHOTO", "NUMBER_PHOTOS", "TIME_TO_SLEEP"
                       , "MODE", "PHOTO_DELAY"
                     };

// Create a variable to hold the picture number. Since the SD card is formatted FAT32, the maximum number of files
// there can be is 65534, so a 16-bit unsigned number will be fine.
uint16_t PIC_COUNT = 0;
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

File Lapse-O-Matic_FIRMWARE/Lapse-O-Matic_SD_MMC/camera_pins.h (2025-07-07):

#if defined(CAMERA_MODEL_WROVER_KIT)
#define PWDN_GPIO_NUM    -1
#define RESET_GPIO_NUM   -1
#define XCLK_GPIO_NUM    21
#define SIOD_GPIO_NUM    26
#define SIOC_GPIO_NUM    27

#define Y9_GPIO_NUM      35
#define Y8_GPIO_NUM      34
#define Y7_GPIO_NUM      39
#define Y6_GPIO_NUM      36
#define Y5_GPIO_NUM      19
#define Y4_GPIO_NUM      18
#define Y3_GPIO_NUM       5
#define Y2_GPIO_NUM       4
#define VSYNC_GPIO_NUM   25
#define HREF_GPIO_NUM    23
#define PCLK_GPIO_NUM    22

#elif defined(CAMERA_MODEL_ESP_EYE)
#define PWDN_GPIO_NUM    -1
#define RESET_GPIO_NUM   -1
#define XCLK_GPIO_NUM    4
#define SIOD_GPIO_NUM    18
#define SIOC_GPIO_NUM    23

#define Y9_GPIO_NUM      36
#define Y8_GPIO_NUM      37
#define Y7_GPIO_NUM      38
#define Y6_GPIO_NUM      39
#define Y5_GPIO_NUM      35
#define Y4_GPIO_NUM      14
#define Y3_GPIO_NUM      13
#define Y2_GPIO_NUM      34
#define VSYNC_GPIO_NUM   5
#define HREF_GPIO_NUM    27
#define PCLK_GPIO_NUM    25

#elif defined(CAMERA_MODEL_M5STACK_PSRAM)
#define PWDN_GPIO_NUM     -1
#define RESET_GPIO_NUM    15
#define XCLK_GPIO_NUM     27
#define SIOD_GPIO_NUM     25
#define SIOC_GPIO_NUM     23

#define Y9_GPIO_NUM       19
#define Y8_GPIO_NUM       36
#define Y7_GPIO_NUM       18
#define Y6_GPIO_NUM       39
#define Y5_GPIO_NUM        5
#define Y4_GPIO_NUM       34
#define Y3_GPIO_NUM       35
#define Y2_GPIO_NUM       32
#define VSYNC_GPIO_NUM    22
#define HREF_GPIO_NUM     26
#define PCLK_GPIO_NUM     21

#elif defined(CAMERA_MODEL_M5STACK_WIDE)
#define PWDN_GPIO_NUM     -1
#define RESET_GPIO_NUM    15
#define XCLK_GPIO_NUM     27
#define SIOD_GPIO_NUM     22
#define SIOC_GPIO_NUM     23

#define Y9_GPIO_NUM       19
#define Y8_GPIO_NUM       36
#define Y7_GPIO_NUM       18
#define Y6_GPIO_NUM       39
#define Y5_GPIO_NUM        5
#define Y4_GPIO_NUM       34
#define Y3_GPIO_NUM       35
#define Y2_GPIO_NUM       32
#define VSYNC_GPIO_NUM    25
#define HREF_GPIO_NUM     26
#define PCLK_GPIO_NUM     21

#elif defined(CAMERA_MODEL_AI_THINKER)
//#define PWDN_GPIO_NUM     32
//#define RESET_GPIO_NUM    -1
//#define XCLK_GPIO_NUM      0
//#define SIOD_GPIO_NUM     26
//#define SIOC_GPIO_NUM     27
//
//#define Y9_GPIO_NUM       35
//#define Y8_GPIO_NUM       34
//#define Y7_GPIO_NUM       39
//#define Y6_GPIO_NUM       36
//#define Y5_GPIO_NUM       21
//#define Y4_GPIO_NUM       19
//#define Y3_GPIO_NUM       18
//#define Y2_GPIO_NUM        5
//#define VSYNC_GPIO_NUM    25
//#define HREF_GPIO_NUM     23
//#define PCLK_GPIO_NUM     22

// The following defines are for the ESP32-Cam AI-THINKER module only. I haven't tried any others.
#define CAM_PIN_PWDN    32
#define CAM_PIN_RESET   -1
#define CAM_PIN_XCLK    0
#define CAM_PIN_SIOD    26
#define CAM_PIN_SIOC    27
#define CAM_PIN_D7      35
#define CAM_PIN_D6      34
#define CAM_PIN_D5      39
#define CAM_PIN_D4      36
#define CAM_PIN_D3      21
#define CAM_PIN_D2      19
#define CAM_PIN_D1      18
#define CAM_PIN_D0       5
#define CAM_PIN_VSYNC   25
#define CAM_PIN_HREF    23
#define CAM_PIN_PCLK    22




#endif

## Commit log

2020-08-31 Initial comit of PCB and Firmware
    [WildlifeCamera_PCB-2020-08-20-16-40-13.sch, WildlifeCamera_PCB.kicad_pcb, WildlifeCamera_PCB.sch]
2020-08-31 Updated Schematic
    [WildlifeCamera_PCB.sch]
2020-09-01 Updated with RTC for filename
    [WildlifeCamera_PCB.sch]
2020-09-02 PCB update
    Sorted most footprints. Put Items in correct places. Not yet routed
    [WildlifeCamera_PCB.kicad_pcb, WildlifeCamera_PCB.sch]
2020-09-04 Updated firmware with SD error logging
    [WildlifeCamera_PCB.kicad_pcb, WildlifeCamera_PCB.sch]
2020-11-21 Update of PCB
    [WildlifeCamera_PCB-B_Cu.gbr, WildlifeCamera_PCB-B_Mask.gbr, WildlifeCamera_PCB-B_SilkS.gbr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]
2020-12-05 Update of code - sorting libraries
    [WildlifeCamera_PCB.kicad_pcb, WildlifeCamera_PCB.sch]
2020-12-18 Large update with email sending code
    [WildlifeCamera_PCB.kicad_pcb]
2021-07-19 Added new PCB design
    Add on for solar charger module. Lapse-O-Matic
    [Lapse_O_Matic_PCB.kicad_pcb, Lapse_O_Matic_PCB.sch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]
2021-07-20 Small updates to PCB
    [Lapse_O_Matic_PCB.sch, WildlifeCamera_PCB.kicad_pcb]
2021-08-12 PCB updates
    Updated PCB
    [Lapse_O_Matic_PCB-B_Cu.gbr, Lapse_O_Matic_PCB-B_Mask.gbr, Lapse_O_Matic_PCB-B_Paste.gbr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]
2021-12-22 updated PCB and hardware
    [Lapse_O_Matic_PCB-B_Cu.gbr, Lapse_O_Matic_PCB-B_Mask.gbr, Lapse_O_Matic_PCB-B_Paste.gbr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]
2022-01-18 Big update of PCB and Code
    [Lapse_O_Matic_PCB-B_Cu.gbr, Lapse_O_Matic_PCB-B_Mask.gbr, Lapse_O_Matic_PCB-B_Paste.gbr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]
2022-01-28 updated code and hardware
    sorted issues with PIR trigger - electrical noise from wifi. Stop wifi. wait then sleep. no retrigger!
    [Lapse-O-Matic_Firebase.ino]
2022-02-03 Updated hardware and firmware
    Better code for PIR enable
    Redesigned whole baseplate design
    [Lapse-O-Matic_Firebase.ino, config.h, lapseomatic.cpp]
2025-07-07 Large update of code to Jul 2025
    [Lapse_O_Matic_PCB.kicad_sch]
